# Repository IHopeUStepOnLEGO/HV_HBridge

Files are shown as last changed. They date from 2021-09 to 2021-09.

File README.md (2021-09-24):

# HV_HBridge

Kicad project for an high voltage h-bridge to produce an 300V AC square wave signal from given input pwm.

The used dc-dc regulator will transform a input voltage of 0 - 12V linearly up to 0-300V. 

Since the dc-dc regulator can deliver up to 1W max, the current will not exceed 3.33mA in 300V application.

This project was used to test the dielectric hold force between the plates of an variable capacitor.

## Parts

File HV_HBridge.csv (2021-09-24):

Reference | Quantity | Value | Footprint | Datasheet | MFN
C1 C2 | 2 | 100n 25V | Capacitor_SMD:C_0603_1608Metric | https://www.mouser.de/datasheet/2/212/KEM_C1005_Y5V_SMD-1101305.pdf | 80-C0603C104Z3VAC
C3 C4 | 2 | 1u 630V | Capacitor_THT:C_Rect_L9.0mm_W9.5mm_P7.50mm_MKT | https://www.mouser.de/datasheet/2/315/ABD0000C255-1131244.pdf | 667-ECW-FD2J105QB
C5 C6 C7 C8 | 4 | 100n 630V | Capacitor_SMD:C_1210_3225Metric | https://www.mouser.de/datasheet/2/212/KEM_C1010_X7R_HV_SMD-1102742.pdf | 80-C1210C104KBR
D3 D4 D9 D10 | 4 | D | HBREMS_Hbridge:SOD-323 | https://www.mouser.de/datasheet/2/1057/BAS70WS-1869683.pdf | 241-BAS70WS_R1_00001
D1 D2 D5 D6 D7 D8 | 6 | BAS101 | Package_TO_SOT_SMD:SOT-23
J1 J2 J4 J5 J6 J7 | 6 | Conn_01x01_Male | MountingHole:MountingHole_2.7mm_M2.5_ISO7380_Pad | ~
J3 | 1 | Conn_01x04 | Connector_PinHeader_2.54mm:PinHeader_1x04_P2.54mm_Vertical | ~
Q1 Q2 Q3 Q4 | 4 | BSS127 | Package_TO_SOT_SMD:SOT-23 | https://www.mouser.de/datasheet/2/196/Infineon-BSS127-DS-v02_01-EN-1226363.pdf | 726-BSS127H6327XTSA2
R1 R2 R3 R4 | 4 | 27R 50V | Resistor_SMD:R_0603_1608Metric | https://www.mouser.de/datasheet/2/54/crxxxxx-1858361.pdf | 652-CR0603FX-27R0ELF
U1 U2 | 2 | IR2104 | Package_SO:SOIC-8_3.9x4.9mm_P1.27mm | https://www.infineon.com/dgdl/ir2104.pdf?fileId=5546d462533600a4015355c7c1c31671 | 942-IR2104SPBF
U3 | 1 | A03P-12 | HBREMS_Hbridge:A03P-12

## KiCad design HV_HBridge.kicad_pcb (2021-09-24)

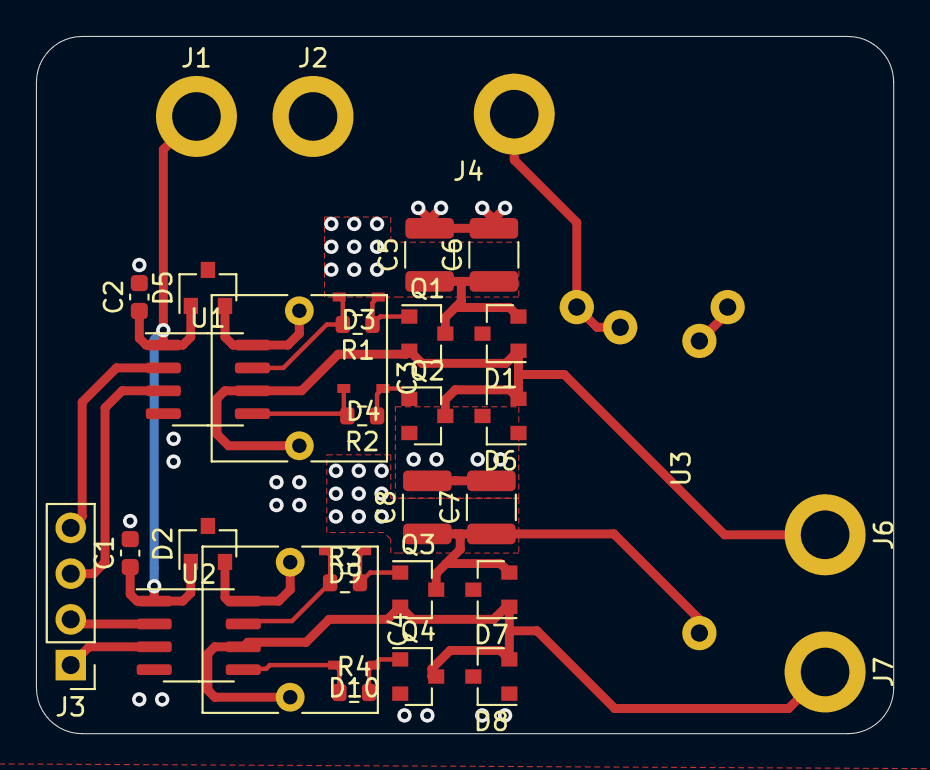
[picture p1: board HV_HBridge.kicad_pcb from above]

Board: 2 copper layers, 47.6 x 38.7 mm, 35 parts (0 on the bottom side), 20 nets.

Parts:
C1, C2: 100n 25V; C_0603_1608Metric
C3, C4: 1u 630V; C_Rect_L9.0mm_W9.5mm_P7.50mm_MKT
C5, C6, C7, C8: 100n 630V; C_1210_3225Metric
D1, D2, D5, D6, D7, D8: BAS101; SOT-23
D3, D4, D9, D10: D; SOD-323
J1, J2, J4, J6, J7: Conn_01x01_Male; MountingHole_2.7mm_M2.5_ISO7380_Pad
J3: Conn_01x04; PinHeader_1x04_P2.54mm_Vertical
Q1, Q2, Q3, Q4: BSS127; SOT-23
R1, R2, R3, R4: 27R 50V; R_0603_1608Metric
U1, U2: IR2104; SOIC-8_3.9x4.9mm_P1.27mm
U3: A03P-12

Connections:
/hbridge1/LOAD1: C3.2, D1.1, D6.2, J6.1, Q1.2, Q2.3, U1.6
/hbridge1/LOAD2: C4.2, D7.1, D8.2, J7.1, Q3.2, Q4.3, U2.6
/hbridge1/PWM1: J3.4, U1.2
/hbridge1/PWM1_EN: J3.3, U1.3
/hbridge1/PWM2: J3.2, U2.2
/hbridge1/PWM2_EN: J3.1, U2.3
GND: C1.2, C2.2, C5.2, C6.2, C7.2, C8.2, D6.1, D8.1, J2.1, Q2.2, Q4.2, U1.4, U2.4, U3.1, U3.4
HS_A: D3.1, R1.2, U1.7
HS_B: D9.1, R3.1, U2.7
LS_A: D4.1, R2.2, U1.5
LS_B: D10.1, R4.1, U2.5
unnamed: C3.1, D5.2, U1.8
unnamed: C4.1, D2.2, U2.8
unnamed: D3.2, Q1.1, R1.1
unnamed: D4.2, Q2.1, R2.1
unnamed: D9.2, Q3.1, R3.2
unnamed: D10.2, Q4.1, R4.2
VCC: C5.1, C6.1, C7.1, C8.1, D1.2, D7.2, Q1.3, Q3.3, U3.3
VDD: C1.1, C2.1, D2.1, D5.1, J1.1, U1.1, U2.1
V_Var: J4.1, U3.2, U3.5

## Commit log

2021-08-19 first update
    [HV_HBridge.sch]
2021-09-24 updated to latest version
    [HV_HBridge.csv, HV_HBridge.kicad_pcb, HV_HBridge.sch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]
2021-09-24 changed board fsilk to 'HV_HBridge'
    [HV_HBridge.kicad_pcb]
